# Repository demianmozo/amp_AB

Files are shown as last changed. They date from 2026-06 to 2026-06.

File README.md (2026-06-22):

# Amplificador de Audio Clase AB





Repositorio con los archivos de diseño, simulación y fabricación de un amplificador de audio Clase AB, desarrollado como proyecto final para la asignatura **Proyecto Transversal V** de la **Universidad Nacional de Mar del Plata (UNMDP)**.

## 👥 Equipo de Trabajo
* **Ian P. Larrieu Lacoste**
* **Augusto Loyza**
* **Demian N. Mozo**

## 📝 Descripción del proyecto
El sistema cuenta con las siguientes características principales:
* **Topología:** Amplificador de potencia de audio Clase AB (utilizando transistores Darlington TIP141/146).
* **PCB:** Diseño simple faz (ruteado en la capa inferior `B.Cu`) pensado para CNC.

## 🛠️ Herramientas utilizadas
* **LTspice:** Simulación eléctrica del circuito y análisis de respuesta en frecuencia.
* **KiCad (v10):** Captura de esquemático y diseño del Layout del PCB (generación de Gerbers y Drill files).

## ⚙️ Notas de fabricación (CNC)
⚠️ **IMPORTANTE:** Para fabricar este PCB en la CNC:

1. **Importar archivos:** Cargar los archivos de cobre (`amp_AB-B_Cu.gbr`), contorno (`amp_AB-Edge_Cuts.gbr`) y los archivos de perforación (`amp_AB-PTH.drl` y `amp_AB-NPTH.drl`).
2. **Espejado (Mirror):** Como el ruteo se diseñó visto desde la capa superior (Top), se deben **seleccionar todos los archivos importados** y espejarlos simultáneamente (respecto al eje X o Y) utilizando la herramienta de FlatCAM. 
3. **Isolation Routing:** Generar las pasadas de la fresa.
4. **Perforación y Corte (Cutout):** Generar los G-Codes correspondientes para los agujeros y el corte del perímetro (`Edge_Cuts`).

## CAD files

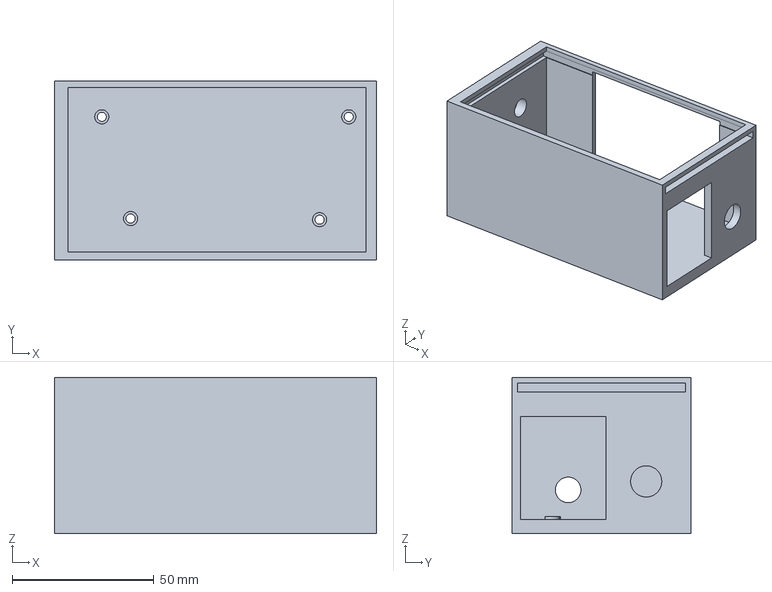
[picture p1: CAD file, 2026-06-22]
Caja ampli.FCStd
113.5 x 63.2 x 55.0 mm

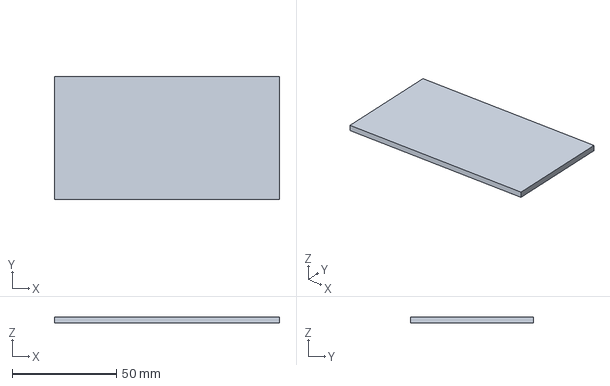
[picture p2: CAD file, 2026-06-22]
Caja Huevistica/Tapa caja ampli.FCStd
108.0 x 59.0 x 3.00 mm

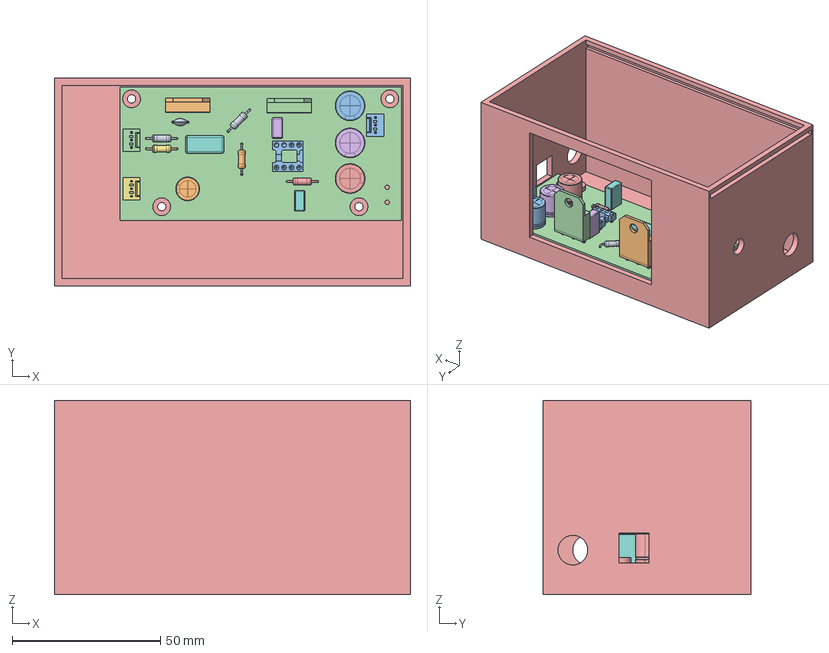
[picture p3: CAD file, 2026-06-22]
case/amp_AB.FCStd
120.0 x 70.0 x 65.5 mm
C_Disc_D50mm_W25mm_P500mm
CP_Radial_D80mm_P350mm
Molex_AE_6410_03A
Molex_AE_6410_03A001
R_Axial_DIN0207_L63mm_D25mm_P1016mm_Horizontal
C_Rect_L70mm_W35mm_P500mm
R_Axial_DIN0207_L63mm_D25mm_P1016mm_Horizontal001
C_Rect_L70mm_W35mm_P500mm001
R_Axial_DIN0207_L63mm_D25mm_P1016mm_Horizontal002
R_Axial_DIN0207_L63mm_D25mm_P1016mm_Horizontal003
CP_Radial_D100mm_P500mm
TO-218-3_Vertical
CP_Radial_D100mm_P500mm001
CP_Radial_D100mm_P500mm002
Molex_AE_6410_03A002
C_Rect_L130mm_W60mm_P1000mm_FKS3_FKP3_MKS4
R_Axial_DIN0207_L63mm_D25mm_P1016mm_Horizontal004
TO-218-3_Vertical002
DIP_8_W762mm_Socket
amp_AB_PCB
Carcasa

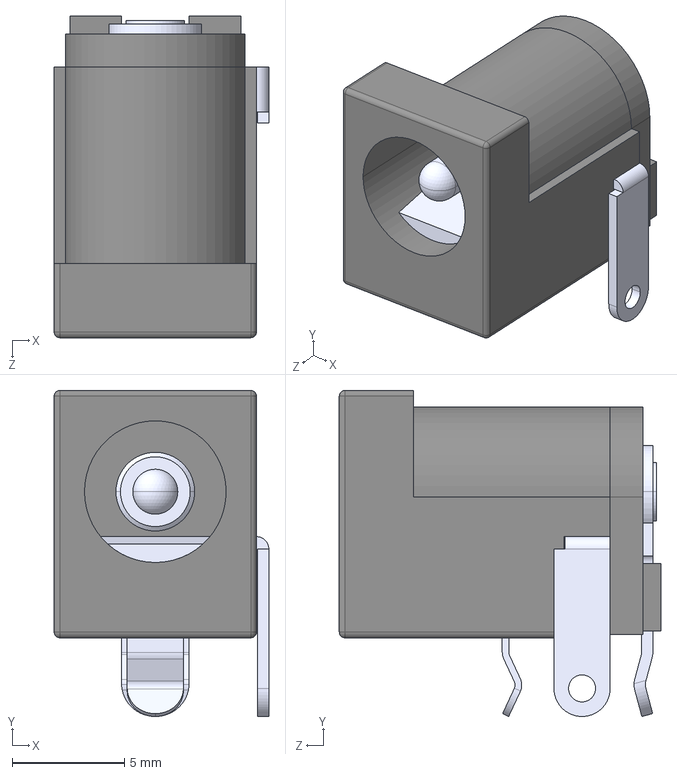
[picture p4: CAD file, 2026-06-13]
DCJ200-10-A-K1-K/DCJ200-10-A-K1-K.step
9.55 x 14.5 x 14.3 mm

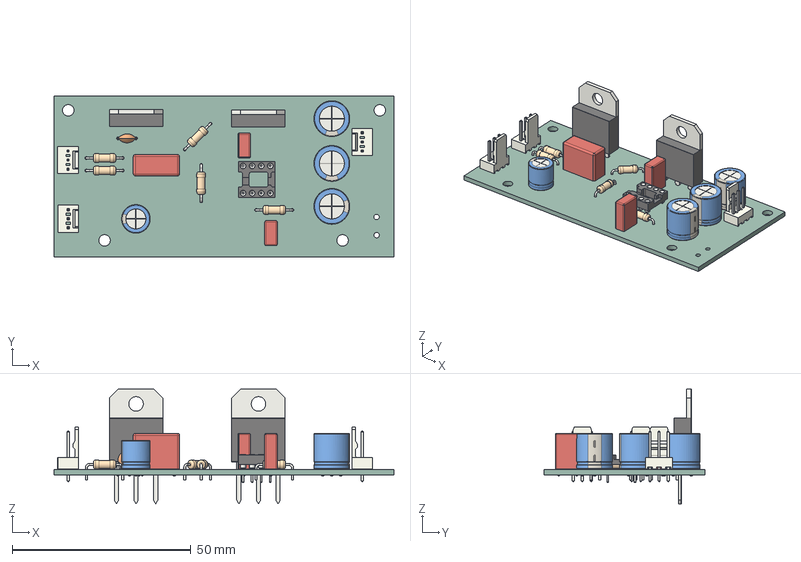
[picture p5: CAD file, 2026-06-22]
.step
95.0 x 45.0 x 32.1 mm
C_Disc_D50mm_W25mm_P500mm
CP_Radial_D80mm_P350mm
Molex_AE_6410_03A x 3
R_Axial_DIN0207_L63mm_D25mm_P1016mm_Horizontal x 5
C_Rect_L70mm_W35mm_P500mm x 2
CP_Radial_D100mm_P500mm x 3
TO-218-3_Vertical x 2
C_Rect_L130mm_W60mm_P1000mm_FKS3_FKP3_MKS4
DIP_8_W762mm_Socket
amp_AB_PCB

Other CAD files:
Caja Huevistica/Caja ampli.FCStd

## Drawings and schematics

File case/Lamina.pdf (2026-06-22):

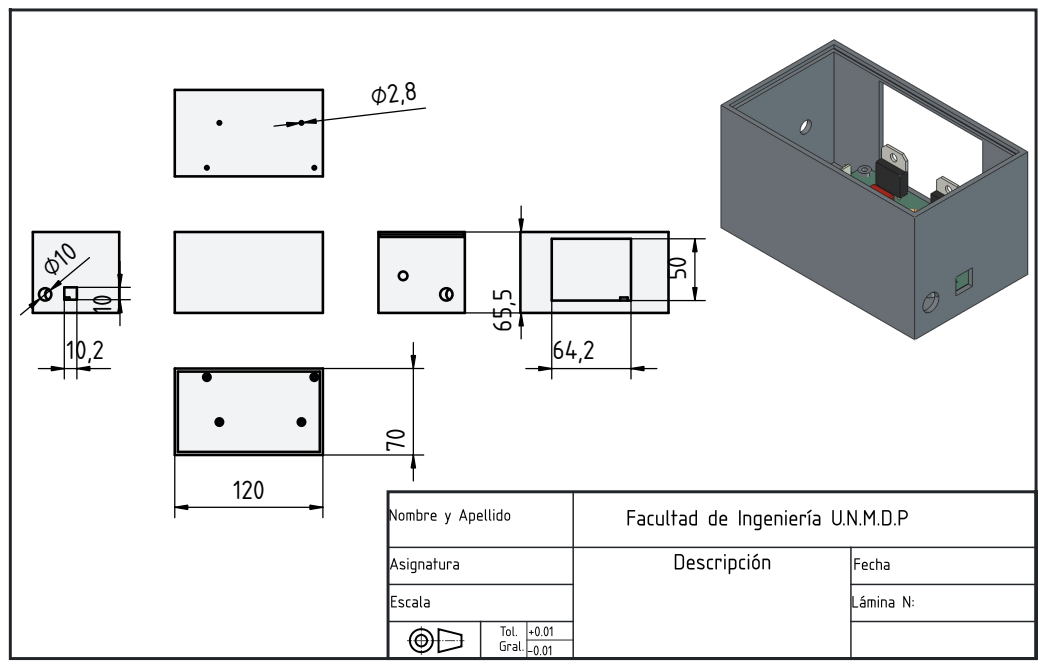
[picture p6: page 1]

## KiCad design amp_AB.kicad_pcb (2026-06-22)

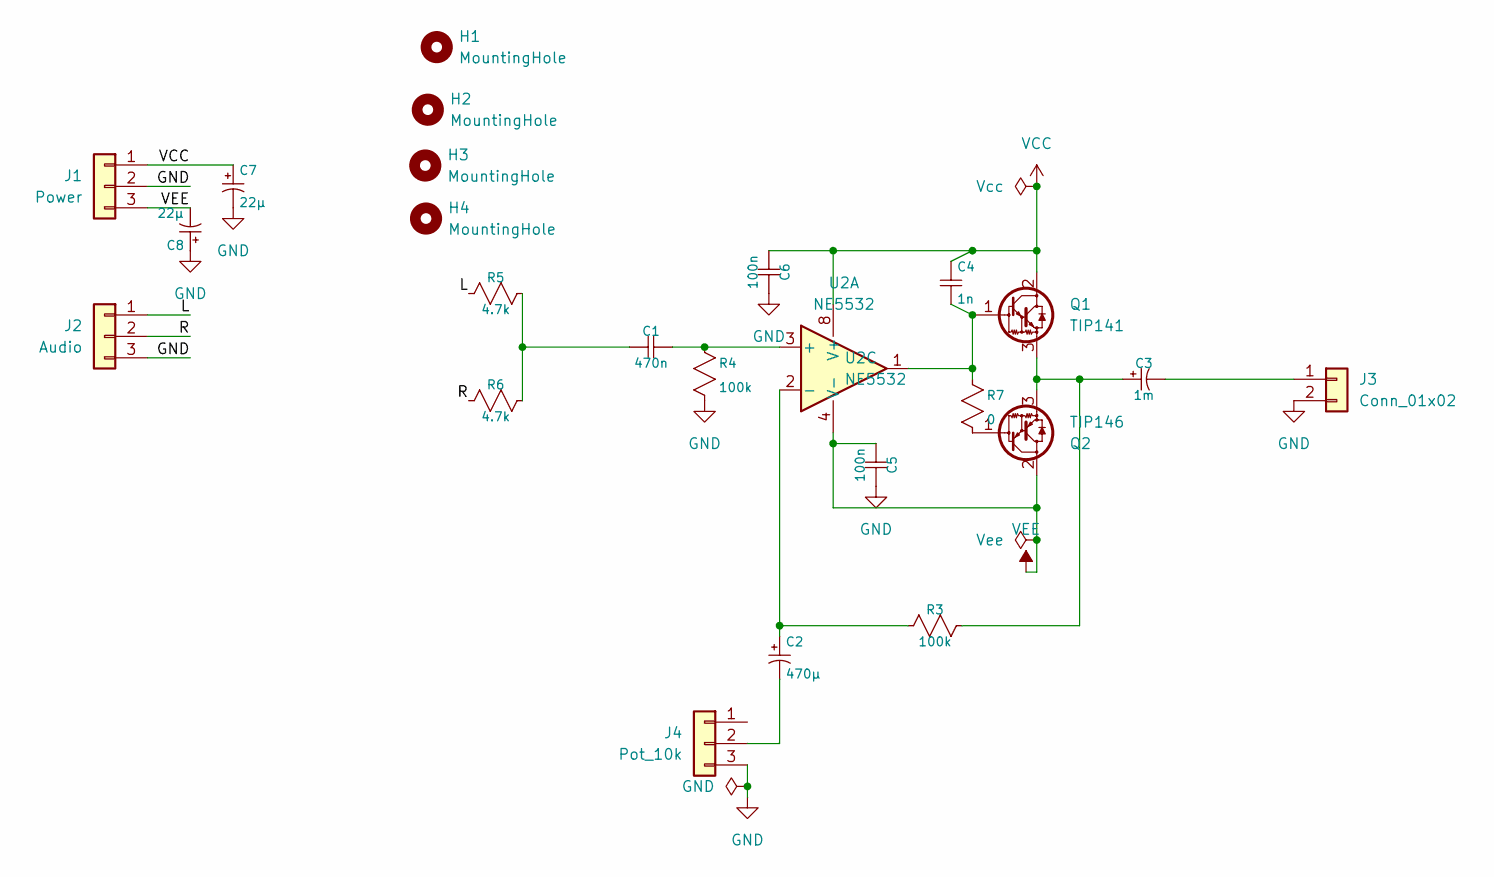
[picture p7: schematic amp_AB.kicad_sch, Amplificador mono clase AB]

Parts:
C1: 470n; C_Rect_L13.0mm_W6.0mm_P10.00mm_FKS3_FKP3_MKS4
C2: 470µ; CP_Radial_D8.0mm_P3.50mm
C3: 1m; CP_Radial_D10.0mm_P5.00mm
C4: 1n; C_Disc_D5.0mm_W2.5mm_P5.00mm
C5: 100n; C_Rect_L7.0mm_W3.5mm_P5.00mm
C6: 100n; C_Rect_L10.0mm_W4.0mm_P7.50mm_MKS4
C7, C8: 22µ; CP_Radial_D10.0mm_P5.00mm
H1, H2, H3, H4: MountingHole; MountingHole_3.2mm_M3
J1: Power; Molex_KK-254_AE-6410-03A_1x03_P2.54mm_Vertical
J2: Audio; Molex_KK-254_AE-6410-03A_1x03_P2.54mm_Vertical
J3: Conn_01x02; TerminalBlock_bornier-2_P5.08mm
J4: Pot_10k; Molex_KK-254_AE-6410-03A_1x03_P2.54mm_Vertical
Q1: TIP141; TO-218-3_Vertical
Q2: TIP146; TO-218-3_Vertical
R3, R4: 100k; R_Axial_DIN0207_L6.3mm_D2.5mm_P10.16mm_Horizontal
R5, R6: 4.7k; R_Axial_DIN0207_L6.3mm_D2.5mm_P10.16mm_Horizontal
R7: 0; R_Axial_DIN0207_L6.3mm_D2.5mm_P10.16mm_Horizontal
U2: NE5532; DIP-8_W7.62mm_Socket

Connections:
/L: J2.1, R5.2
/R: J2.2, R6.2
GND: C5.1, C6.1, C7.2 (B), C8.1 (A), J1.2, J2.3, J3.2, J4.3, R4.2
unnamed: C1.2, R5.1, R6.1
unnamed: C2.1 (A), R3.2, U2.2 (-)
unnamed: C2.2 (B), J4.2
unnamed: C3.1 (A), Q1.3 (E), Q2.3 (E), R3.1
unnamed: C3.2 (B), J3.1
unnamed: C4.2, Q1.1 (B), R7.1, U2.1
unnamed: Q2.1 (B), R7.2
unnamed: C1.1, R4.1, U2.3 (+)
VCC: C4.1, C6.2, C7.1 (A), J1.1, Q1.2 (C), U2.8 (V+)
VEE: C5.2, C8.2 (B), J1.3, Q2.2 (C), U2.4 (V-)

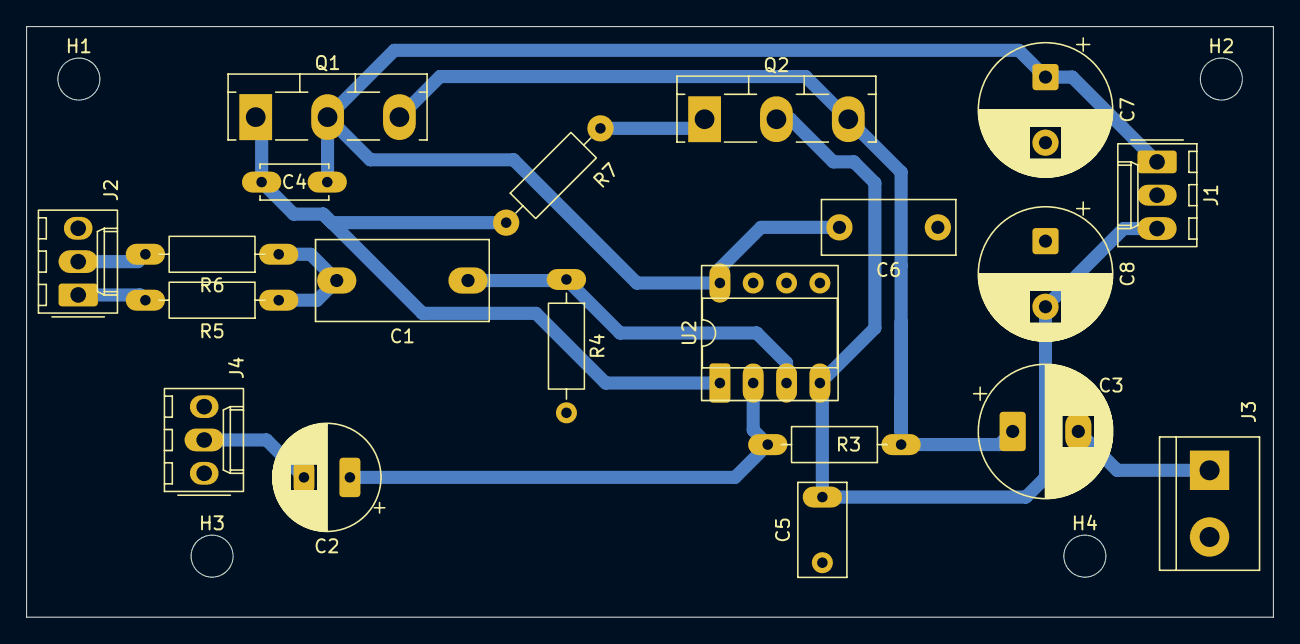
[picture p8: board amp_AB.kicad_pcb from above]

Board: 2 copper layers, 95.0 x 45.0 mm, 24 parts (0 on the bottom side), 13 nets.

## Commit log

2026-06-16 EL HUEVO SAPE
    [amp_AB.kicad_pcb, amp_AB.kicad_sch]
2026-06-18 agregue los footprints faltantes. Esquematico terminado
    [amp_AB.kicad_sch]
2026-06-18 primer diseño de pcb
    [amp_AB.kicad_pcb, amp_AB.kicad_sch]
2026-06-21 Termine el routing y puse los mounting holes
    [amp_AB.kicad_pcb, amp_AB.kicad_sch]
2026-06-21 listo el pollo falta la carcasa
    [amp_AB.kicad_pcb]
2026-06-21 Ultimos detalles y exportado de gerbers
    [amp_AB.kicad_pcb]
2026-06-22 caja huvistica
    [Caja ampli.FCStd]
2026-06-22 Diseño de carcasa en /case
    [.step, amp_AB.FCStd]
2026-06-22 Caja y tapa listos
    [Caja ampli.FCStd, Tapa caja ampli.FCStd]
2026-06-22 Corregidas las islas desconectadas
    [amp_AB.kicad_pcb, amp_AB.kicad_sch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]
